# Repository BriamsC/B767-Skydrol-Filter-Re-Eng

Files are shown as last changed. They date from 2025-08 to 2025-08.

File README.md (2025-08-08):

# B767-Skydrol-Filter-Re-Eng
This project details the reverse engineering of a Skydrol filtration unit from a B767-200. Due to part unavailability, I created 3D models and CAD drawings and performed a feasibility analysis for remanufacturing. This showcases skills in design, analysis, and problem-solving in an aviation context.

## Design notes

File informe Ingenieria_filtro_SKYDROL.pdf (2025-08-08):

INFORME DE INGENIERIA INVERSA: UNIDAD DE FILTRACION DE FLUIDO HIDRAULICO SKYDROL

# Informe de Ingeniería Inversa: Unidad de Filtración de Fluido Hidráulico Skydrol

Ing. Johan Sebastian Barbosa Gonzalez,

# Ing. Briam Said Castro Pietro AS22 Freddy Andrés Bello

# Bogotá D. C. - Colombia

FILTRACION DE FLUIDO HIDRAULICO SKYDROL

# Tabla de contenido

- Introducción
1.1. Antecedentes y Justificación
1.2. Identificación del Componente
1.3. Objetivos del Informe
1.4. Metodología General
- Análisis Funcional y de Diseño
2.1. Descripción General del Sistema
2.2. Principio de Funcionamiento
2.3. Análisis Físico y Desmontaje
- Análisis Técnico y de Materiales
3.1. Análisis Dimensional
3.2. Análisis de Materiales
3.3. Análisis del Elemento Filtrante
3.4. Ensamblaje y Estanqueidad
- Especificaciones Técnicas Derivadas
4.1. Especificaciones de Rendimiento
4.2. Especificaciones de Fabricación
- Conclusiones
5.1. Resumen de Hallazgos
5.2. Comparación con Estándares Conocidos
5.3. Factibilidad de Replicación o Reparación
- Recomendaciones
6.1. Recomendaciones para Fabricación
6.2. Recomendaciones para Mantenimiento
6.3. Recomendaciones para Futuros Análisis
- Apéndice
Apéndice A – Registro Fotográfico Detallado
- Planos CAD y Modelado 3D de Piezas

FILTRACION DE FLUIDO HIDRAULICO SKYDROL

# Informe de Ingeniería Inversa: Unidad de Filtración de Fluido Hidráulico Skydrol

### 1.0 Introducción

### 1.1. Antecedentes y Justificación

La unidad de filtración hidráulica objeto de este estudio ha sido identificada como un componente originalmente fabricado por la empresa SOFRANCE, actualmente parte del grupo SAFRAN. Debido a la falta de disponibilidad comercial del componente y la necesidad de asegurar la continuidad operativa del sistema hidráulico en aeronaves, se ha planteado un proceso de ingeniería inversa. El propósito es determinar la viabilidad técnica de reproducción local del sistema, garantizando compatibilidad funcional, integridad estructural y seguridad operacional.

### 1.2. Identificación del Componente

- Designación: Unidad de Filtración Hidráulica con válvula de retención integrada y sensor de presión.
- Número de Parte (P/N): FA02168A
- Número de Serie (S/N): Específico De cada unidad
- Fabricante Original (OEM): SOFRANCE (actualmente SAFRAN)
- Ubicación en la Aeronave: Instalado en el circuito hidráulico principal del POD’s, conectado mediante acoples tipo codo en las líneas de entrada y salida del fluido. Se encuentra fijado mediante pernos a través de perforaciones roscadas con insertos tipo helicoil en la base principal.

### 1.3. Objetivos del Informe

- Documentar la estructura y funcionamiento del sistema.
- Generar modelos CAD 3D de la base principal, el filtro, el soporte cilíndrico y el conjunto válvula.
- Caracterizar materiales y métodos de fabricación utilizados.
- Evaluar la viabilidad técnica de la reproducción del sistema con tecnología disponible localmente.

FILTRACION DE FLUIDO HIDRAULICO SKYDROL

### 1.4. Metodología General

Se realizó una inspección visual inicial, seguido del desmontaje ordenado del componente. Cada subcomponente fue analizado dimensional y materialmente. Se modelaron en 3D las piezas críticas y se identificaron interfaces mecánicas, hidráulicas y electrónicas (sensor de presión). Finalmente, se evaluaron alternativas de fabricación y ensamblaje.

### 2.0 Análisis Funcional y de Diseño

### 2.1. Descripción General del Sistema

El sistema permite el paso del fluido hidráulico Skydrol a través de un filtro desmontable para eliminar partículas contaminantes. La configuración interna direcciona el flujo a través de una base metálica principal y lo canaliza nuevamente hacia la salida, una vez ha sido filtrado.

### 2.2. Principio de Funcionamiento

El fluido ingresa por un puerto con acople tipo codo, circula por una galería interna hacia el filtro, y luego retorna hacia la salida.

- El filtro se sostiene mediante un soporte cilíndrico que se enrosca en la base central.
- Se incluye una válvula tipo check (retención) compuesta por un balín, un resorte y un tapón metálico, cuya función es evitar el retorno del flujo.
- Se incorpora un sensor de presión directamente en la base central, con una perforación que comunica la cámara del filtro con el cuerpo del sensor.
- Se emplean juntas tóricas tipo O-ring en el tapón, el soporte cilíndrico y las conexiones de entrada y salida para asegurar la estanqueidad.
- Las perforaciones de fijación a la estructura cuentan con roscas internas reforzadas con inserts helicoidales (tipo helicoil).

### 2.3. Análisis Físico y Desmontaje

- Inspección Visual: El sistema presenta un diseño compacto, con superficie tratada (posiblemente anodizada o pasivada).
- Desmontaje: Se extrajo el soporte cilíndrico roscado, permitiendo el acceso al elemento filtrante. Posteriormente se desmontó la válvula tipo check y el sensor de presión.
- Subcomponentes Identificados:
- Base principal (material: acero o aleación resistente)
- Soporte cilíndrico roscado (material Acero)
- Elemento filtrante (Malla filtrante, elemento filtrante)

FILTRACION DE FLUIDO HIDRAULICO SKYDROL

- Conjunto válvula de retención (balín, resorte, tapón)
- Sensor de presión con comunicación directa al paso del fluido
- Juntas tóricas en puntos críticos
- Conexiones tipo codo en entrada/salida
- Insertos tipo helicoil en perforaciones roscadas de fijación

### 3.0 Análisis Técnico y de Materiales

### 3.1. Análisis Dimensional

El análisis dimensional fue realizado mediante herramientas de medición directa (calibrador, micrómetro y profundímetro). Se elaboraron modelos CAD 3D preliminares de las piezas clave: base principal, soporte cilíndrico, tapón de válvula y alojamiento del sensor de presión. Estos modelos servirán como base para los planos técnicos y la simulación de ensamblaje.

### 3.2. Análisis de Materiales

Las observaciones iniciales permiten inferir el uso de diferentes materiales según la función de cada componente. Para una verificación precisa se recomienda realizar espectrometría de emisión óptica (OES) o análisis por fluorescencia de rayos X (XRF).

Tabla 2. Identificación preliminar de materiales

Subcomponente | Función | Material Aparente | Método sugerido de verificación
Base principal | Soporte estructural y paso hidráulico | Acero inoxidable | Espectrometría / análisis metalográfico
Soporte cilíndrico | Sujeción del filtro | Acero o aluminio | Dureza / densidad / XRF
Tapón de válvula | Retención del resorte y balín | Aluminio | XRF / Densidad / Conductividad térmica
Balín | Elemento de cierre (válvula check) | Acero templado | Prueba de dureza / magnetismo
Resorte | Retorno del balín en válvula check | Acero para resorte | Microscopia / resistencia mecánica
Sensor de presión | Medición directa de presión hidráulica | Electrónico, cuerpo metálico | Confirmación por referencia técnica
Juntas tipo O-ring | Sellado en zonas de presión | Elastómero (Viton/EPDM) | Ensayo de compatibilidad con Skydrol

### 3.3. Análisis del Elemento Filtrante

FILTRACION DE FLUIDO HIDRAULICO SKYDROL

El filtro no fue descrito en detalle, por lo que se considera como componente crítico pendiente de análisis específico. No obstante, se puede establecer la siguiente estructura para su caracterización:

Característica | Descripción esperada | Método de Análisis Propuesto
Tipo de medio filtrante | Malla metálica y elemento filtrante. | Corte transversal + análisis microscópico
Grado de filtración (micras) | [Por determinar] | Prueba en banco con partícula patrón
Eficiencia (Beta ratio) | [Ideal >75-100] | Si es posible, ensayo controlado
Construcción del cartucho | Plegado, encapsulado, soldado | Desmontaje y análisis físico

### 3.4. Ensamblaje y Estanqueidad

- Las uniones roscadas (tapón, soporte cilíndrico) cuentan con juntas tóricas tipo O-ring para garantizar la estanqueidad del sistema bajo presión.
- Se identificaron insertos tipo helicoil en la base principal, utilizados para mejorar la resistencia de las roscas al torque de fijación.
- Las conexiones hidráulicas en entrada y salida del sistema están hechas mediante acoples tipo codo, que permiten flexibilidad en el montaje en zonas confinadas de la aeronave.

### 4.0 Especificaciones Técnicas Derivadas

### 4.1. Especificaciones de Rendimiento

Estas especificaciones se establecen a partir del análisis del diseño del componente y de parámetros estándar en sistemas de filtración hidráulica aeronáutica compatibles con Skydrol. Algunos valores deben ser confirmados mediante pruebas o documentación del OEM si se logra acceder a ella.

Parámetro | Valor Estimado / Esperado | Observaciones
Presión de operación nominal | 3000 psi (206.8 bar) | Valor impreso en el flitro
Presión de operación máxima | 4500 psi (310.2 bar) | Valor impreso en el flitro
Temperatura | de
operación
-54 °C a +135 °C | Rango compatible con Skydrol

FILTRACION DE FLUIDO HIDRAULICO SKYDROL

Tipo | de | fluido
compatible

Skydrol LD-4, Skydrol
500B-4

Confirmar compatibilidad con sellos y materiales

### 4.2. Especificaciones de Fabricación

Esta sub-sección presenta los procesos de manufactura sugeridos para cada subcomponente, basados en su geometría, función y materiales.

Subcomponente | Material Aparente | Proceso de Fabricación Recomendado | Observaciones
Base principal | Acero inoxidable | Mecanizado CNC / Brochado / Perforado | Puede requerir tratamientos anticorrosivos
Soporte cilíndrico | Aluminio / Acero | Torneado CNC + roscado | Debe garantizar alineación y sellado
Tapón de válvula | Aluminio | Torneado CNC / Moleteado / Taladrado | Ligero y mecanizable fácilmente
Balín | Acero templado | Pieza estándar (no requiere fabricación) | Usar esferas calibradas grado A
Resorte | Acero para resorte | Compra estándar / fabricación por enrollado | Confirmar coeficiente de rigidez
Juntas tóricas | Viton o EPDM | Compra estándar | Compatibilidad con Skydrol
Sensor de presión | Electrónico, metálico | Comercial | Fijación al soporte por medio de tres roscas M6x1 o similar
Inserto helicoidal | Acero inoxidable | Comercial (helicoil) | Mejora resistencia de roscas

Nota técnica: La selección de materiales y procesos debe garantizar compatibilidad total con Skydrol, ya que este fluido es altamente agresivo frente a ciertos elastómeros y metales no tratados. Se recomienda incluir pruebas específicas de resistencia química para cualquier modificación propuesta.

### 5.0 Conclusiones

### 5.1. Resumen de Hallazgos

FILTRACION DE FLUIDO HIDRAULICO SKYDROL

Del proceso de ingeniería inversa realizado sobre la unidad de filtración hidráulica compatible con Skydrol, fabricada originalmente por SOFRANCE (actualmente SAFRAN), se obtuvieron los siguientes hallazgos clave:

- La unidad se compone de una base principal mecanizada en aluminio, que integra el paso del fluido, alojamiento del filtro, el sensor de presión y una válvula tipo check.
- El sistema de filtración utiliza un soporte cilíndrico enroscado para fijar el filtro, con sellado mediante juntas tipo O-ring.
- La válvula check se compone de un balín, un resorte y un tapón, este último con alta probabilidad de ser aluminio mecanizado.
- El sensor de presión toma lectura directa mediante una perforación que comunica el paso del fluido con su alojamiento roscado.
- Las conexiones hidráulicas externas están aseguradas mediante acoples tipo codo.
- Se identificó el uso de inserts helicoidales (tipo helicoil) en las perforaciones de fijación para mejorar la durabilidad de las roscas.
- Las propiedades funcionales del sistema corresponden a condiciones estándar de operación en aeronaves (presiones de hasta 3000–5000 psi y compatibilidad con Skydrol).

### 5.2. Comparación con Estándares Conocidos

Característica | Normativa o Referencia Estándar | Estado Actual del Componente
Compatibilidad química (fluido Skydrol) | ASTM D471 / AMS 3217 | Parcialmente verificado
Presión de operación | SAE AS5440 / MIL-H-5440 | Alineado con valores típicos
Integridad estructural (roscas) | NAS1130 / NASM33537 (helicoil) | Conforme al uso de insertos helicoidales
Sensor de presión | MIL-PRF-62121 / RTCA DO-160 | No verificado aún (pendiente análisis funcional)

Se requiere una validación más profunda de los materiales usados, especialmente en sellos y elementos filtrantes, para confirmar su cumplimiento normativo y compatibilidad total con entornos aeronáuticos.

### 5.3. Factibilidad de Replicación o Reparación

FILTRACION DE FLUIDO HIDRAULICO SKYDROL

Con base en el análisis realizado, se concluye que sí es técnicamente viable la reproducción del sistema bajo las siguientes condiciones:

- Disponibilidad de procesos de mecanizado CNC de alta precisión para la base principal y subcomponentes.
- Adquisición de balines y resortes de grado industrial estandarizado.
- Fabricación local o adquisición externa del elemento filtrante, sujeto a análisis de su estructura y medio filtrante.
- Confirmación mediante pruebas de los materiales elastoméricos seleccionados para las juntas, garantizando su resistencia a Skydrol.
- Reemplazo del sensor de presión por un equivalente comercial, calibrado según el rango de presión del sistema.

### 6.0 Recomendaciones

### 6.1. Recomendaciones para Fabricación

Para la producción o reproducción de la unidad de filtración hidráulica, se recomiendan las siguientes acciones y parámetros:

Ítem | Recomendación
Material de la base principal | Acero inoxidable AISI 316L o equivalente, con pasivado posterior.
Soporte cilíndrico | Aluminio 6061-T6 anodizado, mecanizado por torno CNC.
Tapón de válvula | Aluminio anodizado o acero 1045 con tratamiento anticorrosión.
Balin | Acero inoxidable templado (esfera calibrada DIN 5401 Grado G10).
Resorte | Acero para resorte tipo AISI 302 o Inconel X750 (según carga).
Juntas tóricas | Viton (FKM) o EPDM compatible con Skydrol, según ASTM D2000.
Roscas | Incluir inserts helicoidales tipo Helicoil en zonas críticas.
Sensor de presión | Sustituible por sensor comercial, con el mimo sistema de fijación al soporte, o equivalente en electrónica, modificando sistema de fijación a la estructura.

Se sugiere realizar prototipado inicial en impresión 3D (material resistente a químicos) para validación dimensional previa al mecanizado.

### 6.2. Recomendaciones para Mantenimiento

Con el fin de preservar la funcionalidad del sistema y prevenir fallas por contaminación o degradación de componentes, se recomienda:

FILTRACION DE FLUIDO HIDRAULICO SKYDROL

Elemento | Acción Sugerida
Elemento filtrante | Inspección visual y/o reemplazo
Sensor de presión | Calibración y verificación funcional
Válvula check | Prueba de estanqueidad / limpieza interna
Juntas O-ring | Sustitución preventiva
Estructura de soporte | Revisión de fisuras o corrosión

### 6.3. Recomendaciones para Futuros Análisis

Área de Estudio | Acción Propuesta
Elemento filtrante | Caracterización completa del medio filtrante (micras, tipo, construcción).
Pruebas de compatibilidad química | Ensayos con Skydrol para juntas, adhesivos y materiales propuestos.
Ensayos de presión y flujo | Pruebas en banco para confirmar presión de trabajo y caudal nominal.
Simulación por elementos finitos (FEA) | Análisis estructural de la base y tapón bajo presión máxima prevista.
Documentación de trazabilidad | Establecer control documental (planos, fichas, certificados de materiales).
Validación aeronáutica | Consultar con autoridad competente para homologación o uso experimental.

Nota Final: Se recomienda establecer una cadena de suministro confiable para piezas estándar (resortes, balines, sensores, O-rings) y considerar la fabricación bajo norma AS9100 o ISO 9001 para asegurar calidad aeronáutica.

### 7.0 Apéndice

Apéndice A – Registro Fotográfico Detallado

Fotografías tomadas durante la inspección visual, desmontaje y análisis físico del sistema.

FILTRACION DE FLUIDO HIDRAULICO SKYDROL

- | Vista | general | del | componente | completo | montado

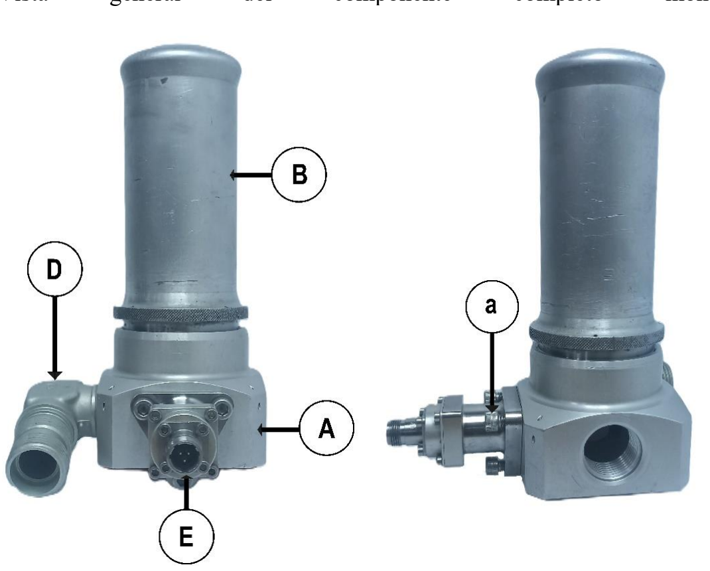
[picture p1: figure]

A | Foto A-01, A-02 | Base Principal / Soporte Central | Estructura principal que aloja todos los componentes y gestiona los conductos de entrada, salida y paso hacia el filtro.
B | Foto B-01 | Soporte Cilíndrico / Carcasa | Contiene y sella el elemento filtrante (C). Su montaje roscado permite el acceso para el reemplazo del filtro.
D | Foto D-01, D-02 | Acople tipo Codo (x2) | Proporciona la interfaz de conexión en ángulo para las líneas hidráulicas externas de entrada y salida del sistema.
E | Foto E-01 | Sensor de Presión | Mide la presión del fluido para monitorear el estado del sistema. Su ubicación sugiere una medición de presión diferencial para detectar colmatación del filtro.
a | Foto a-01 | Tornillos de Fijación del Sensor (x3) | Aseguran el sensor de presión (E) firmemente contra la base principal (A), garantizando un sellado correcto.

FILTRACION DE FLUIDO HIDRAULICO SKYDROL

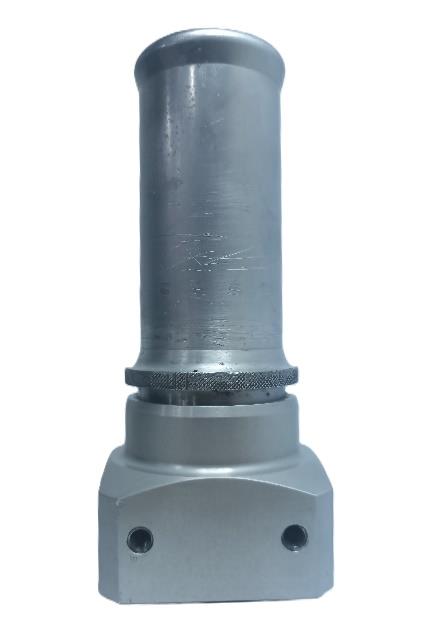
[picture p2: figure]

- Fotografías del sistema desmontado (por fases)
- Detalles de:
- Base principal (cara superior e inferior)

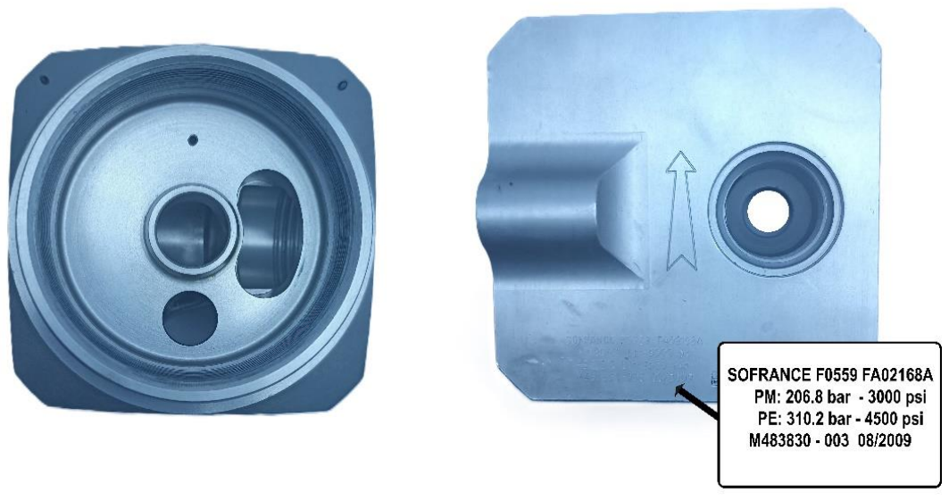
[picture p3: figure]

- Soporte cilíndrico

FILTRACION DE FLUIDO HIDRAULICO SKYDROL

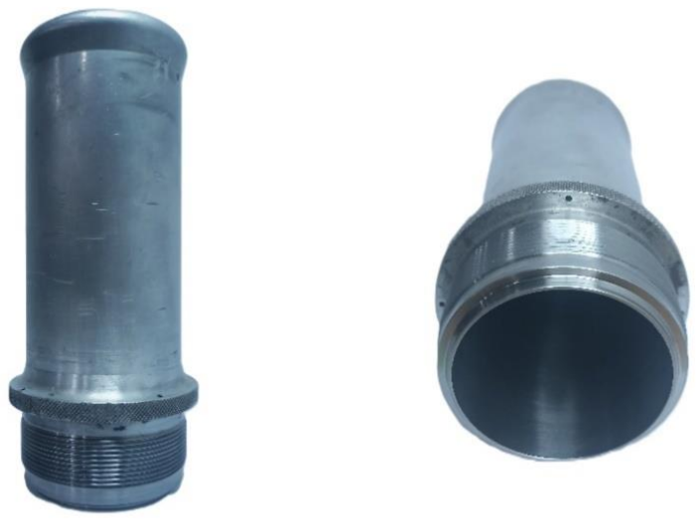
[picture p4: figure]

- Elemento filtrante.

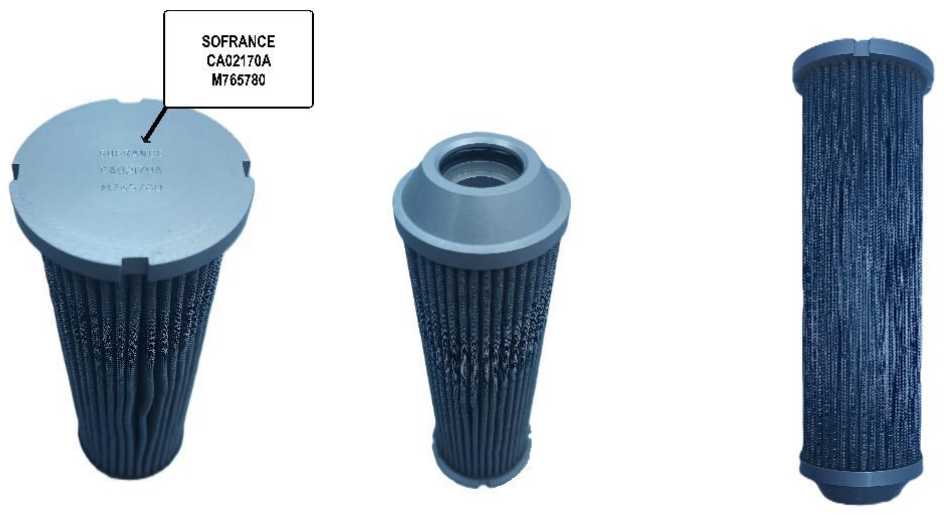
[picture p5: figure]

- Válvula check (balín, resorte, tapón)

FILTRACION DE FLUIDO HIDRAULICO SKYDROL

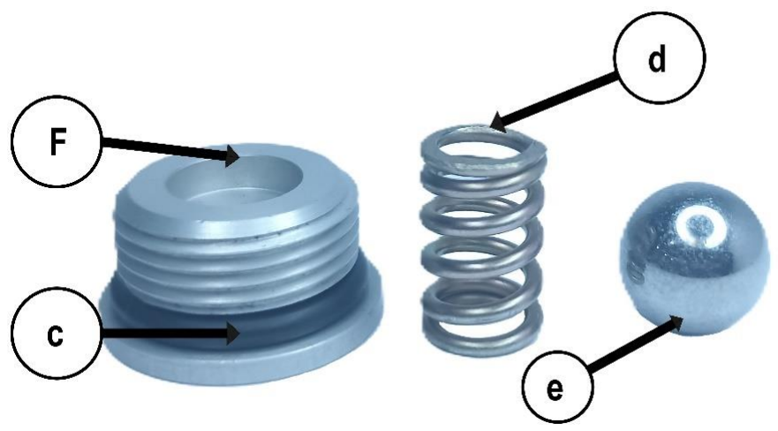
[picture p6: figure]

F | Foto F-01 | Tapón de la Válvula de Retención | Sella el alojamiento de la válvula de retención y proporciona la precarga mecánica necesaria para el resorte (d).
c | Foto c-01 | Junta Tórica Tapon sistema check (O-ring) | Proporciona el sello estático principal entre el tapon del sistema de valvula check y la Base Principal (A).
d | Foto d-01 | Resorte de la Válvula de Retención | Ejerce una fuerza constante sobre el balín (e) para mantener la válvula cerrada hasta que la presión del fluido supere dicha fuerza.
e | Foto e-01 | Balín / Esfera de Obturación | Elemento móvil que actúa como obturador. Al ser empujado por el resorte (d), sella el paso de fluido en la válvula de retención.
- Sensor de presión y canal de comunicación

FILTRACION DE FLUIDO HIDRAULICO SKYDROL

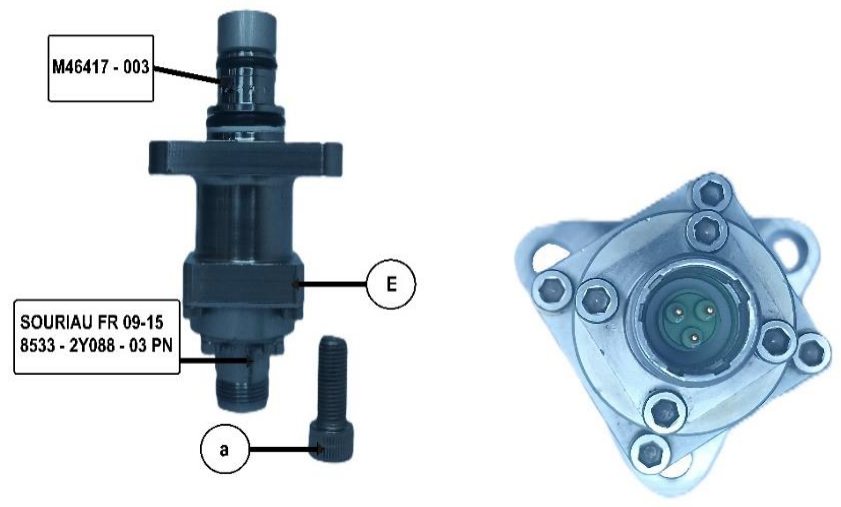
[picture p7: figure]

E | Foto E-01 | Sensor de Presión | Mide la presión del fluido para monitorear el estado del sistema. Su ubicación sugiere una medición de presión diferencial para detectar colmatación del filtro.
a | Foto a-01 | Tornillos de Fijación del Sensor (x3) | Aseguran el sensor de presión (E) firmemente contra la base principal (A), garantizando un sellado correcto.
- Acoples tipo codo

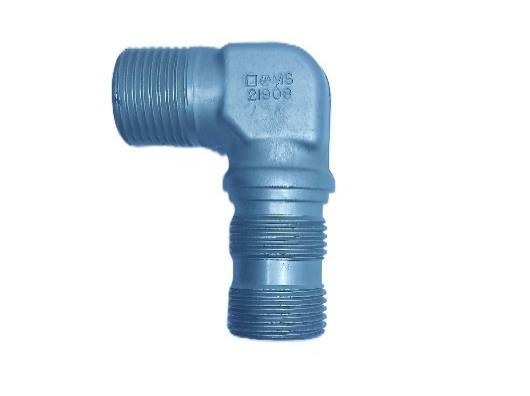
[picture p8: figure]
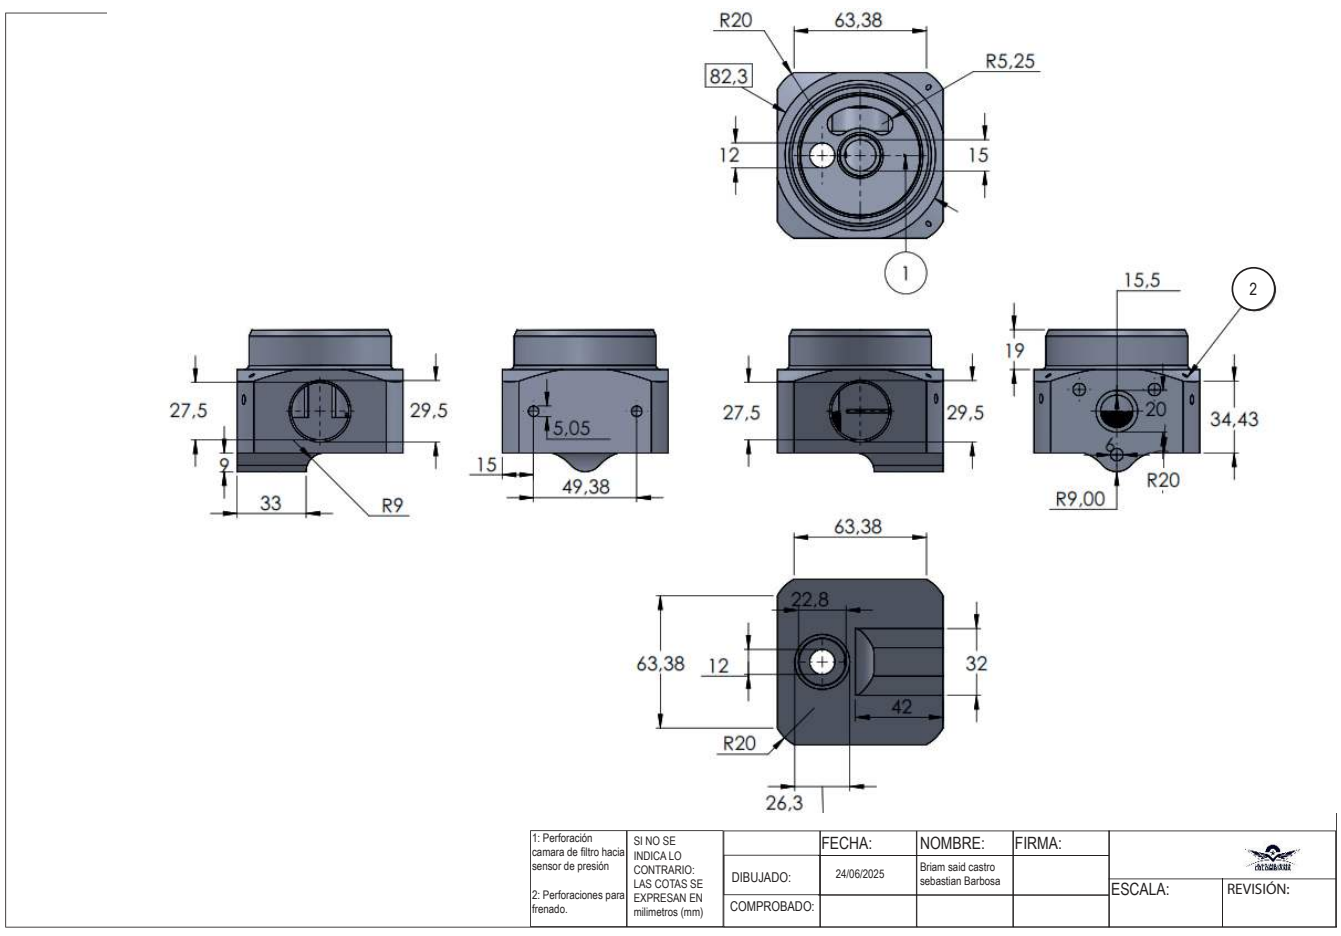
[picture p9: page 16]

1: Perforación camara de filtro hacia sensor de presión 2: Perforaciones para frenado. | SI NO SE INDICA LO CONTRARIO: LAS COTAS SE EXPRESAN EN milimetros (mm) | | FECHA: | NOMBRE: | FIRMA:

DIBUJADO: | | Briam said castro sebastian Barbosa 24/06/2025

ESCALA: | REVISIÓN:

COMPROBADO:

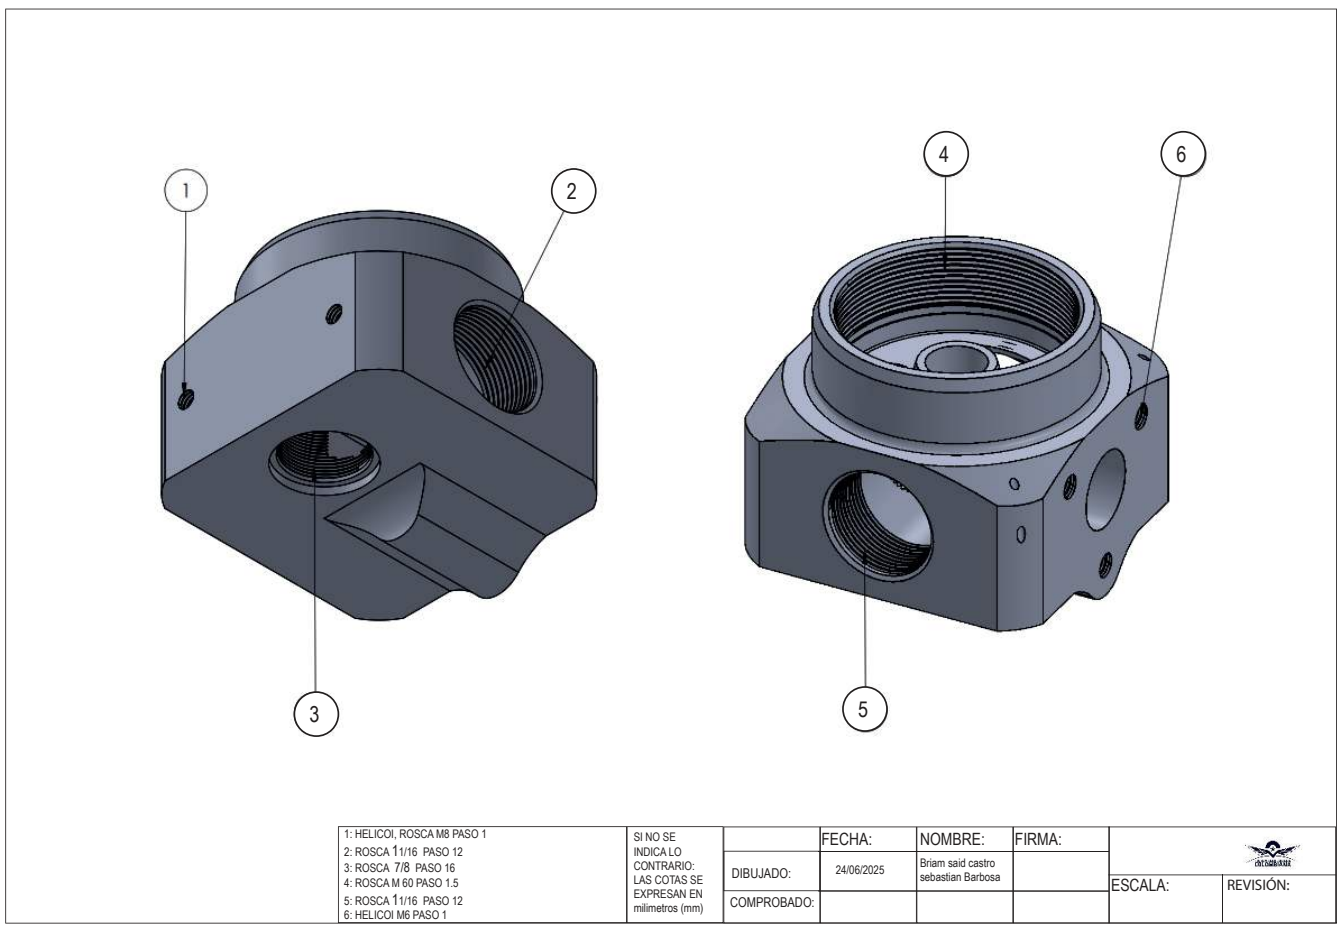
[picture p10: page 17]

1: HELICOI, ROSCA M8 PASO 1 2: ROSCA 11/16 PASO 12 3: ROSCA 7/8 PASO 16 4: ROSCA M 60 PASO 1.5 5: ROSCA 11/16 PASO 12 6: HELICOI M6 PASO 1 | SI NO SE INDICA LO CONTRARIO: LAS COTAS SE EXPRESAN EN milimetros (mm) | | FECHA: | NOMBRE: | FIRMA:

DIBUJADO: | | Briam said castro sebastian Barbosa 24/06/2025

ESCALA: | REVISIÓN:

COMPROBADO:

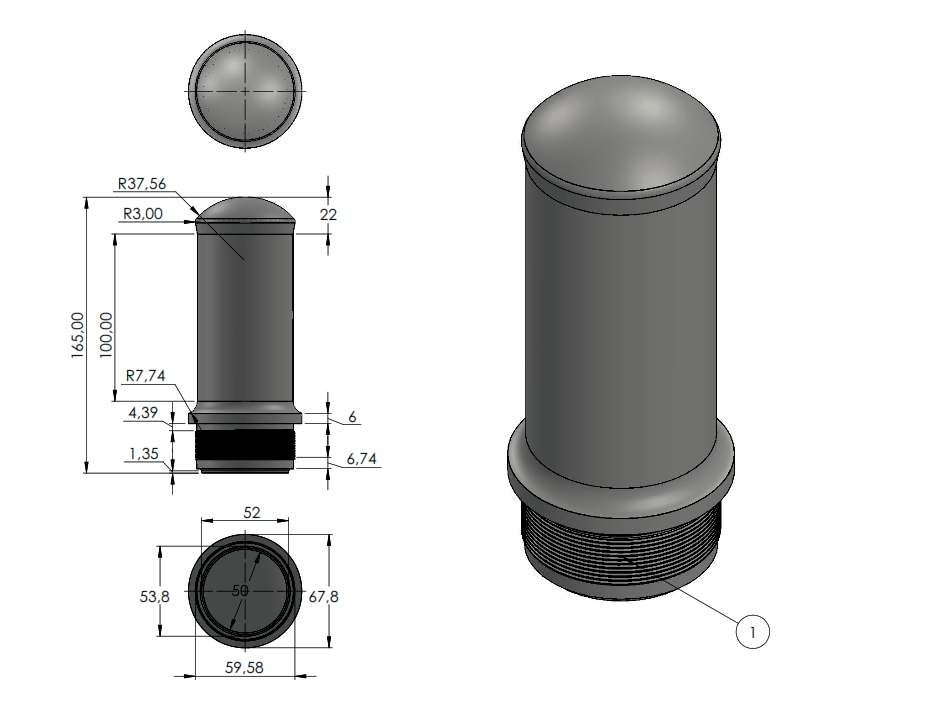
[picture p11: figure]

ESCALA: | REVISIÓN:
1: ROSCA M 60 PASO 1.5 | SI NO SE INDICA LO CONTRARIO: LAS COTAS SE EXPRESAN EN milimetros (mm) | | FECHA: | NOMBRE: | FIRMA:
| | DIBUJADO: | | Briam said castro sebastian Barbosa 24/06/2025
| | COMPROBADO:

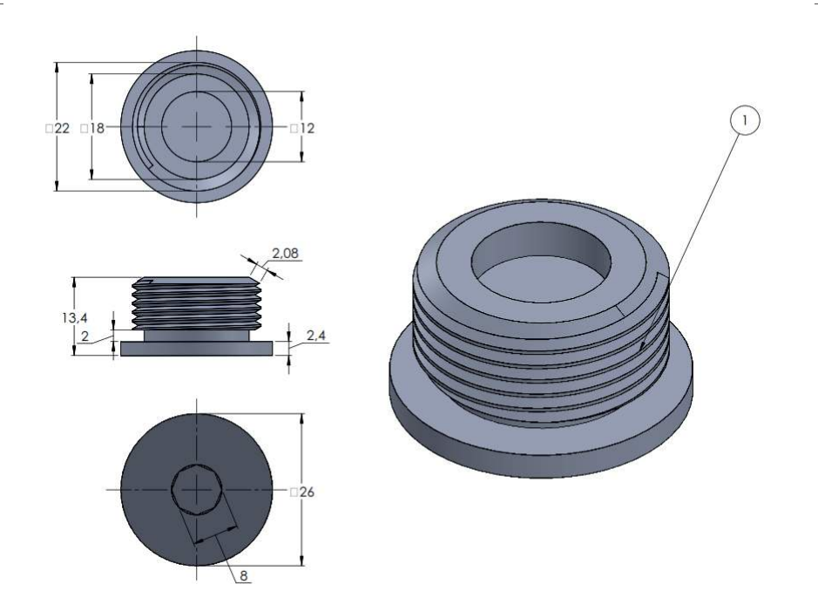
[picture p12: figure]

ESCALA: | REVISIÓN:
1: ROSCA M22 PASO 1.5 | SI NO SE INDICA LO CONTRARIO: LAS COTAS SE EXPRESAN EN milimetros (mm) | | FECHA: | NOMBRE: | FIRMA:
| | DIBUJADO: | | Briam said castro sebastian Barbosa 24/06/2025
| | COMPROBADO:

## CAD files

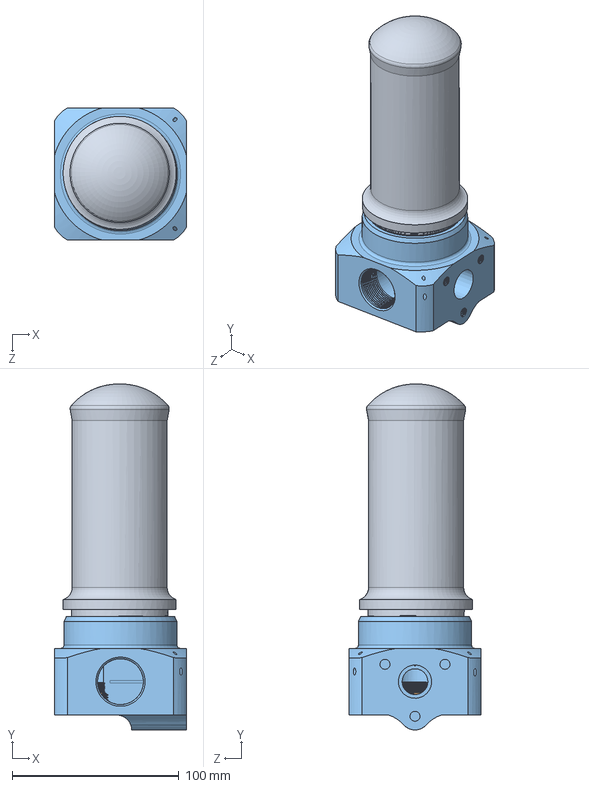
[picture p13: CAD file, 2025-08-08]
Assem1.SLDASM
79.4 x 207.5 x 79.4 mm
tapon
FILTRO

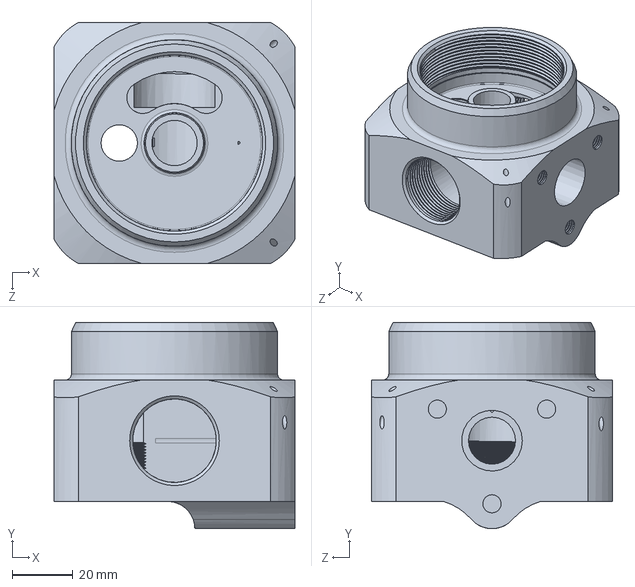
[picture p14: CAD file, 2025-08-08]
Part2.SLDPRT
79.4 x 68.0 x 79.4 mm

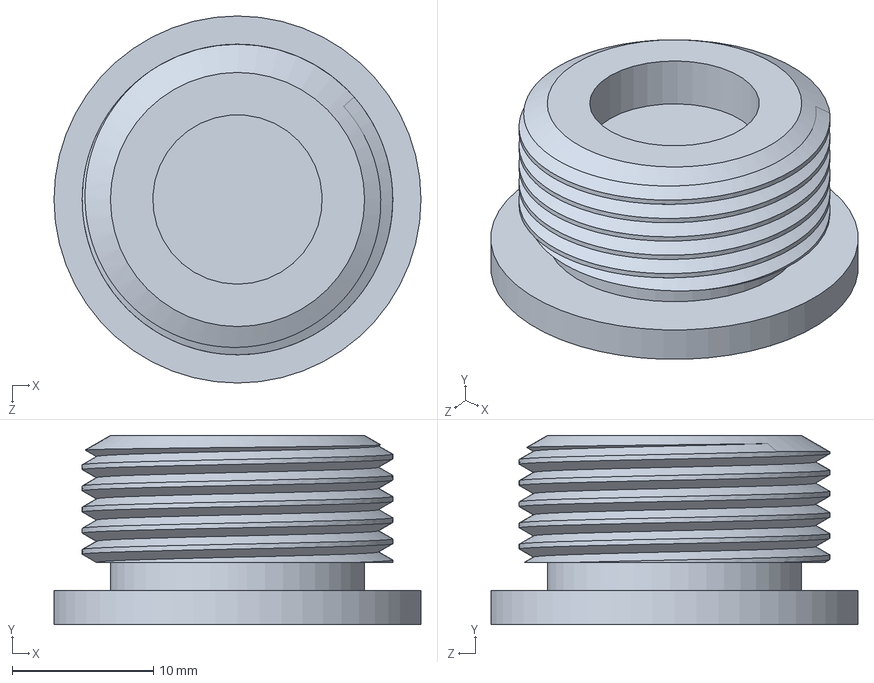
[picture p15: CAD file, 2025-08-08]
tapon.SLDPRT
26.0 x 13.4 x 26.0 mm

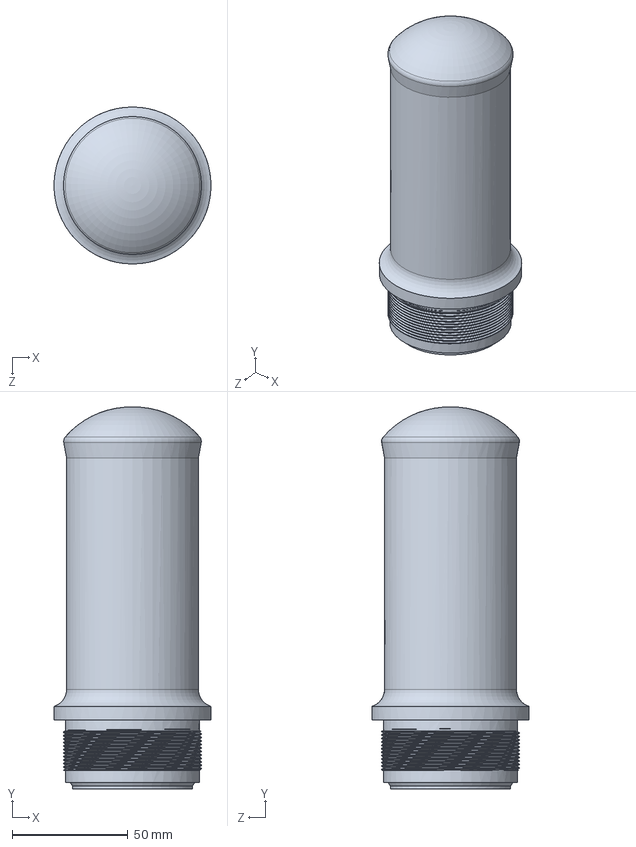
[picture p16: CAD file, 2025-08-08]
FILTRO.SLDPRT
67.8 x 165.0 x 67.8 mm
